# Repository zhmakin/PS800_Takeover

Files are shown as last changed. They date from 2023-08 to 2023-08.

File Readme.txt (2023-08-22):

1. Matlab:
	|..slprj
	|..Buck800w_v1.slx
	|..Buck800w_v1.slxc
	|..sd_setup_v1.m

	*.m - parameter file with model settings 
	*.slx - model file with simulation model

2. Power Inductor design - 3D models of the custom inductor. No design calculation is there. 

3. Releases - folder with the ordering files and fabrication outputs and info we had in the moment of the first version ordering.

4. Ver 2 - Folder with materials collected for second version of the converter. There are RFQs, requirements document, sMath file with calculation design and mostly datasheets for cheapest components available.

5. Manual.pdf - communication and pluging in instruction for the board.

6. Project_STM32G4x.zip - STM CPU firmware project.

7. PS800.zip - PC software to debug and manage the board via USART interface.

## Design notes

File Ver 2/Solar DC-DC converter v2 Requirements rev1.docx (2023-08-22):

Solar DC-DC converter.

Technical requirements

Rev. 0.1

Revision history

Revision level | 0.1
Release date | 12-jul-2023
Status | Draft
Owner | Aleksei Z

Version | Date | Description | Originator
0.1 | 12-jul-2023 | Initial | Aleksei Z

List of abbreviations/acronyms

DC | Direct current
EMC | Electromagnetic compatibility
IP | Ingress protection
PCB | Printed circuit board

1. General requirements
  1.1. Subject of current requirements is a non-isolated bidirectional DCDC power converter for solar application.
  1.2. Converter shall have two sets of terminals to connect two solar PV panels in parallel
  1.3. Converter shall have one set of terminals to connect Li-Ion battery
  1.4. Converter shall have one set of terminals to connect power inverter
  1.5. Minimal cost shall be in priority
  1.6. Interaction with inverter MPPT algorithms is not a subject of current development.
  1.7. The packaging should be made as an open PCB design with heat sink attached
  1.8. Context diagram:

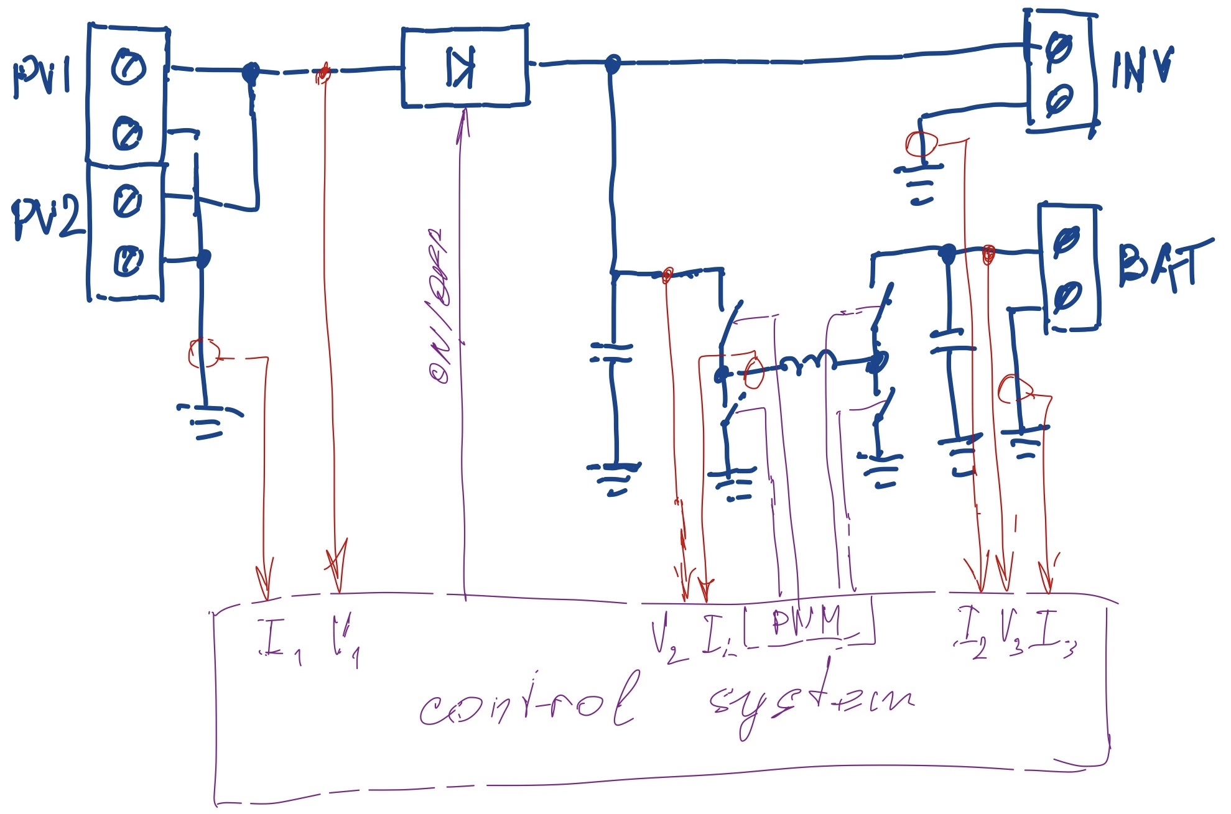
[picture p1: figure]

2. Electrical requirements

# | Parameter | Min | Nom | Max | Units

AA | Inverter output power | | | 900 | W
AB | Inverter output current | | | 30 | A
| 2 x Solar panel RSP450D-120
A | Output voltage | 24 | 34.7 | 43 | V
B | Current total (per panel) | | | 26 (13) | A
| Li-Ion battery (JB-LFP24-100CC as a reference)
C | Battery voltage | 20 | 24 | 26.4 | V
D | Battery charge voltage | | 29 | | V
E | Battery charge current | 1 | | 30 | A
| Power converter set-points
F | PV support voltage | | 34 | | V
G | Short circuit protection delay | | 500 | | us
H | Battery under/overvoltage protection delay | | 500 | | us
I | Overcurrent protection delay | | 1 | | s
J | Overcurrent level | | 110 | | %

3. Environmental requirements
  3.1. Converter shall operate within temperature range of -30°C to +65°C.
  3.2. Converter shall have ingress protection not less than IP54 in line with IEC60529.
4. Functional requirements
    4.1.1. The converter PV input must have “ideal diode” circuitry to prevent reverse current.
  4.1. The converter must have communication interfaces:
    4.1.1. 1 x UART (non-isolated),115 kbps, 8N1, 3.3V-level
    4.1.2. 1 x SPI (non-isolated), 1Mbps, 3.3V-level
  4.2. The converter shall have sufficient modes of operation:
    4.2.1. Battery charge automatic mode (solar to battery and solar to inverter power flows)
      4.2.1.1. Control logic shall provide constant voltage with current limit operation (CV/CC)
      4.2.1.2. Voltage and current set-points should be set via communication interface
      4.2.1.3. Charge mode should start automatically if converter is not in IDLE
      4.2.1.4. MPPT tracking of the PV panels should be implemented
      4.2.1.5. Maximum charge power set-point shall be set via communication interface
    4.2.2. PV support mode (battery to inverter power node)
      4.2.2.1. The control strategy shall be constant voltage with current limit operation (CV/CC).
      4.2.2.2. Transition to this mode and voltage/current set-points are managed via communication interface.
    4.2.3. Converter IDLE mode (Inverter supplied with solar power only)
      4.2.3.1. Transition to IDLE shall be available via communication interface command or by the protection logic.
      4.2.3.2. Only transition via communication interface command to another mode of operation is possible.
  4.3. The converter shall have protection functionality
    4.3.1. Short circuit protection

The control logic shall shutoff the converter in 2.E after short circuit is determined. Protection reset via communication interface shall be implemented.

    4.3.2. Battery undervoltage protection

Stop discharge if battery voltage reached its minimum value for more than 2.H. No automatic transition to another mode.

    4.3.3. Battery overvoltage protection

Stop charge if battery voltage goes at least 0.1V above maximum charge voltage level (2.D) during more than 2.H

    4.3.4. Reverse current to PV panels protection
    4.3.5. Overcurrent protection
      4.3.5.1. The converter shall go to IDLE mode if overcurrent level 2.J reached and kept during more than 2.I
      4.3.5.2. Protection reset shall be available via communication interface only
5. Mechanical requirements
  5.1. All terminals shall be placed along bottom side of the PCB (assumed wall mounted device)
  5.2. Natural convection only shall be used to cool down
  5.3. Power stage shall be designed on separated PCB
  5.4. Cable glands can be used to comply with IP rating

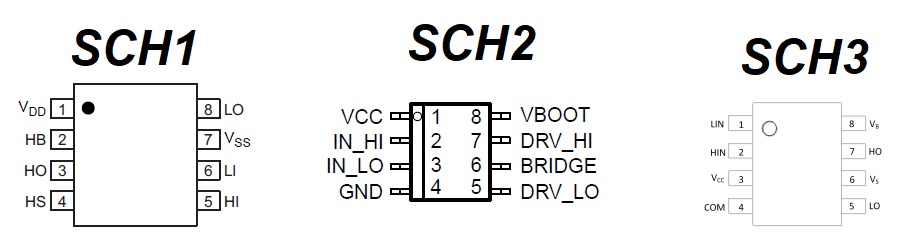
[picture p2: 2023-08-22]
Ver 2/Parts/Drivers/Schematics.jpg

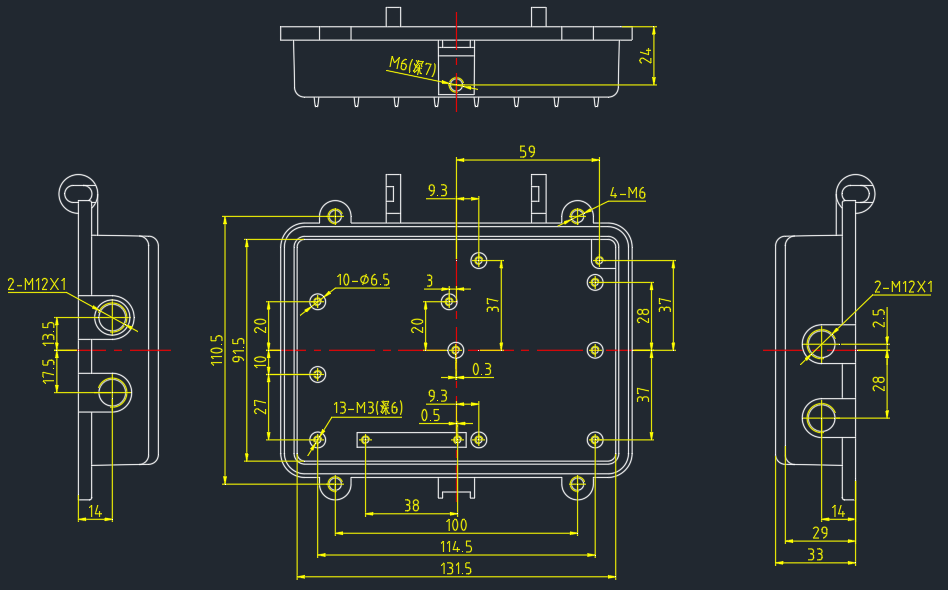
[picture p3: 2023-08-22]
Ver 2/RFQ/He95bb1689c3447e7890ed621c03901dcM.png

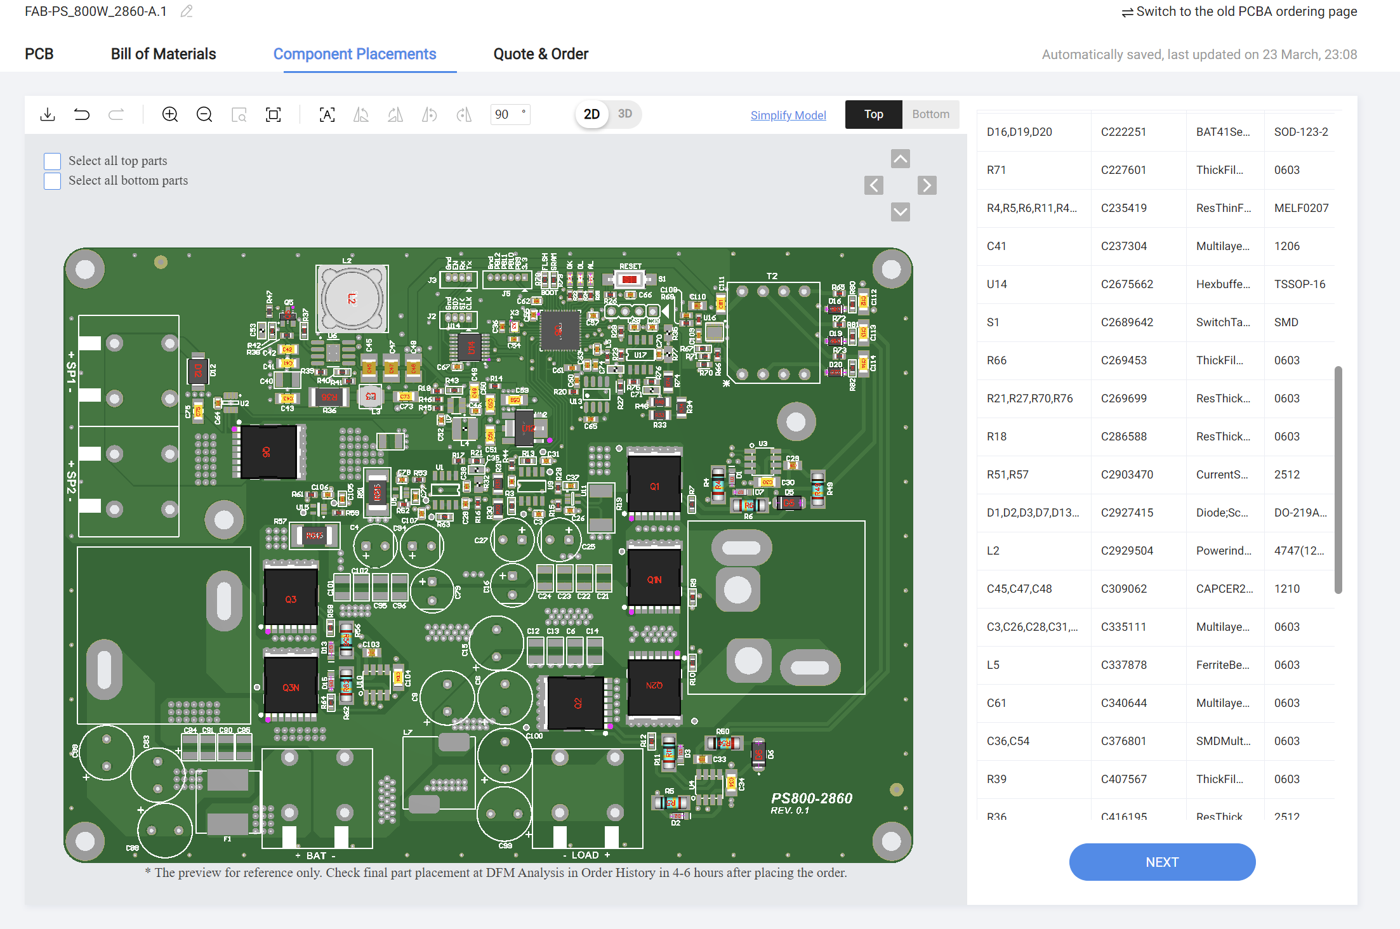
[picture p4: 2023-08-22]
Releases/01/Screenshot_1.png

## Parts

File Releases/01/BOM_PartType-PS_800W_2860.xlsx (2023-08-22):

Designator | Part Number | Footprint | Comment | Quantity
C1, C2, C81 | C3216C0G2E682J160AA | 1206 | Multilayer Ceramic Capacitors MLCC - SMD/SMT 1206 250V 6800pF C0G 5% T: 1.6mm | 3
C3, C26, C28, C31, C38, C39, C44, C46, C52, C55, C56, C57, C62, C63, C64, C66, C67, C68, C69, C70, C78, C106, C107 | C1608X7R1H104K080AA | 0603 | Multilayer Ceramic Capacitors MLCC - SMD/SMT 0603 50VDC 0.1uF 10% X7R 0.8mm | 23
C5, C11, C17, C18, C43, C73, C75, C80, C86, C92, C97 | CC1206KKX7R0BB104 | 1206 | Multilayer Ceramic Capacitors MLCC - SMD/SMT 100V 0.1uF X7R 1206 10% | 11
C6, C12, C13, C14, C21, C22, C23, C24, C40, C76, C84, C85, C90, C91, C95, C96, C101, C102 | C3225X7R2A106K250AC | 1210 | Multilayer Ceramic Capacitors MLCC - SMD/SMT 1210 100VDC 10uF 10% X7R | 18
C7, C20, C41, C82, C93 | GRM31CC72A475KE11L | 1206 | Multilayer Ceramic Capacitors MLCC - SMD/SMT 4.7UF 100V 10% 1206 | 5
C10, C19, C42, C87, C98 | GRM31MR72A684KA35L | 1206 | Multilayer Ceramic Capacitors MLCC - SMD/SMT 0.68uF 100VDC 10% X7R | 5
C29, C33, C103, C110 | CL21B225KAFNNNF | 0805 | Multilayer Ceramic Capacitors MLCC - SMD/SMT 2.2uF+/-10% 25V X7R 0805 | 4
C30, C34, C59, C104, C112, C113, C114 | CL31B475KAHNNNF | 1206 | Multilayer Ceramic Capacitors MLCC - SMD/SMT 4.7uF+/-10% 25V X7R 1206 | 7
C32, C35, C53, C71 | CC0603JPX7R9BB103 | 0603 | Cap Ceramic 0.01uF 50V X7R 5% SMD 0603 125C Paper T/R | 4
C36, C54 | 06035A6R8CAT2A | 0603 | SMD Multilayer Ceramic Capacitor, 6.8 pF, 0.25pF, C0G / NP0, 50 V, 0603 [1608 Metric] | 2
C37, C77, C105 | CC0603JRNPO9BN471 | 0603 | Multilayer Ceramic Capacitors MLCC - SMD/SMT 470PF 50V 5% 0603 | 3
C45, C47, C48 | CL32B226KAJNNNE | 1210 | CAP CER 22UF 25V 10% X7R 1210 | 3
C49, C50, C51, C58, C111 | CL31B106KAHNNNE | 1206 | CL31 Series 10 uF 25 V ±10 % Tolerance X7R SMT Multilayer Ceramic Capacitor | 5
C60, C65 | CL10B225KP8NNNC | 0603 | Ceramic capacitor SMD 0603 2.2 µF 10 V 10 % Samsung Electro-Mechanics CL10B225KP8NNNC 4000 pc(s) | 2
C61 | 0603N102J500CT | 0603 | Multilayer Ceramic Capacitor, 1000 pF, 5%, C0G / NP0, 50 V, 0603 [1608 Metric] | 1
C72 | 08052C472KAT2A | 0805 | CAP CER 4700PF 200V 10% X7R 0805 | 1
C74 | CL10B105MO8NNWC | 0603 | Prices include import duty and tax. CAP, 1UF, 16V, MLCC, 0603; SVHC: No SVHC (15-Jan-2019) | 1
C108 | C0603C682K5RACTU | 0603 | 0603 X7R ceramic capacitor, 50V 6.8nF | 1
C109 | 06033C473KAT4A | 0603 | Multilayer Ceramic Capacitors MLCC - SMD/SMT 25volts 0.047uF 10% X7R | 1
D1, D2, D3, D7, D13, D15, D18 | MSS1P6-M3/89A | DO-219AD-2 | Diode; Schottky Barrier; Vr 60V; If 1A; Pkg MicroSMP; Vf 0.52V; Cj 40pF; Tj +150degc | 7
D4 | LTST-C190KSKT | 0603 | Standard LEDs - SMD Yellow Clear 587nm | 1
D8 | LTST-C190KGKT | 0603 | Standard LEDs - SMD Green Clear 571nm | 1
D10 | LTST-C190KRKT | 0603 | Standard LEDs - SMD Red Clear 631nm | 1
D5, D6, D14 | SS1H10-E3/5AT | SMA (DO-214AC) | 100V 1A | 3
D12 | SMBJ48CA | DO-214AA-2 | Diode Transient Voltage Suppressor Single Directional 48 Volt 600W 2-Pin DO-214AA Tape and Reel | 1
D16, D19, D20 | BAT41ZFILM | SOD-123-2 | BAT41 Series 200 mA 1 V Schottky Diode Surface Mount - SOD-123 | 3
D17 | BZD27C27P-E3-08 | DO-219AB-2 | Diode Zener Single 27V 800mW 2-Pin DO-219AB T/R | 1
F1 | 3-139-124 | SMD | Fuse, Fast-Acting, SMD, High-Current, 80V DC, 60A, UHP Series | 1
L2 | MSS1210-683MEB | 4747 (1212 metric) | Power inductor, shielded, 10/20% tol, SMT, RoHS | 1
L3 | NRS4018T100MDGJ | 4018 | Inductor Power Shielded Wirewound 10uH 20% 100KHz Ferrite 1.2A 180mOhm DCR 1515 T/R | 1
L4 | NRS4018T3R3MDGJ | 4018 | Inductor Power Shielded Wirewound 3.3uH 20% 100KHz Ferrite 2A 66mOhm DCR 1515 T/R | 1
L5 | BLM18AG151SH1D | 0603 | Ferrite Beads Multi-Layer 150Ohm 25% 100MHz 500mA 250mOhm DCR 0603 Paper T/R | 1
L7 | 7443091100 | SMD | WE-HCM SMT High Current Flat Wire Inductor | 1
Q1, Q1N, Q2, Q2N, Q3, Q3N, Q6 | FDBL86066-F085 | TO-LL8-8 | N-Channel PowerTrench® MOSFET, 80V, 300A, 1.4mΩ | 7
Q5 | 2N7002-7-F | SOT-23-3 | 2N7002-7-F N-Channel MOSFET, 115 mA, 60 V, 3-Pin SOT-23 Diodes Inc | 1
R1, R2, R4, R5, R6, R11, R49, R50, R55, R56, R60, R62 | MMB02070C3008FB200 | MELF 0207 | Res Thin Film 0207(2309) 3 Ohm 1% 0.4W ±50ppm/C Conformal Melf SMD Automotive Medical Blister T/R | 12
R3, R7, R9, R10, R12, R13, R37, R40, R42, R43, R58, R63, R64, R67, R78, R79, R80, R81, R82 | RK73H1JTTD1002F | 0603 | Resistor Thick Film 0603 10K Ohm 1% 1/10W ±100ppm/°C SMD Punched Paper Tape and Reel | 19
R14 | RC0603JR-100RL | 0603 | YAGEO RC0603JR-100RL THICK FILM RESISTOR, 0 OHM, 100mW, 5% | 1
R15, R16, R28, R44, R53, R61, R65, R72, R73 | RC0603FR-071RL | 0603 | Res Thick Film 1.6 x 0.8 mm 1 Ohm 1% 0.1W(1/10W) 200ppm/ C Molded SMD Paper T/R | 9
R17, R23, R26, R29, R47, R52, R59, R75 | AC0603FR-13100RL | 0603 | AC Series 0603 100 Ohm ±1 % 0.1 W ±100 ppm/°C Surface Mount Thick Film Resistor | 8
R18 | ERJ-3EKF4022V | 0603 | Res Thick Film 1.6 x 0.8 mm 40.2K Ohm 1% 0.1W(1/10W) 100ppm/ C Molded SMD Punched Carrier T/R | 1
R19 | LRMAP2512-R00075FT4 | 2512 | Current Sense Resistors - SMD 3W 0.0007 Ohm 1% | 1
R51, R57 | LRMAP2512-R001FT4 | 2512 | Current Sense Resistors - SMD 3W 1 mOhm 1% Metal Strip resistor | 2
R20 | CRCW060350R0FKEA | 0603 | Thick Film Resistors - SMD 1/10watt 50ohms 1% Non Std Qt Req'd | 1
R21, R27, R70, R76 | CRCW0603100KFKEAC | 0603 | Res Thick Film 0603 100K Ohm 1% 1/10W ±100ppm/°C Molded SMD Paper T/R | 4
R22, R24, R25 | RK73H1JTTD2550F | 0603 | Thick Film Resistors - SMD 1/10watts 255ohms 1% | 3
R69 | RK73H1JTTD6493F | 0603 | Thick Film Resistors - SMD 1/10watt 649Kohms 1% | 1
R71 | RK73H1JTTD1542F | 0603 | Thick Film Resistors - SMD 1/10watts 15.4Kohms | 1
R30, R31, R33, R34 | RT1206DRE0710KL | 1206 | Thin Film Resistors - SMD | 4
R48, R74 | RT1206DRE0715KL | 1206 | Thin Film Resistors - SMD 15K OHM .5% 50PPM 1/4W | 2
R32, R35, R77 | ERJ-PB6B1001V | 0805 | Res Thick Film 0805 1K Ohm 0.1% 0.25W(1/4W) ±50ppm/C Pad SMD | 3
R36 | RMCF2512FT1R00 | 2512 | Res Thick Film 2512 1 Ohm 1% 1W ±400ppm/°C Molded SMD SMD Plastic T/R | 1
R38 | RC0603JR-07130KL | 0603 | Thick Film Resistors - SMD 130K OHM 5% | 1
R39 | RK73H1JTTD6492F | 0603 | Thick Film Resistors - SMD 1/10watts 64.9Kohms | 1
R41 | RK73H1JTTD1103F | 0603 | Res Thick Film 0603 110K Ohm 1% 0.1W(1/10W) ±100ppm/C Molded SMD Automotive Punched Paper T/R | 1
R66 | RK73H1JTTD1243F | 0603 | Thick Film Resistors - SMD 1/10watt 124Kohms 1% | 1
R68 | RK73H1JTTD5902F | 0603 | Thick Film Resistors - SMD 1/10watts 59Kohms 1% | 1
R45 | AC0603FR-0727KL | 0603 | Thick Film Resistors - SMD 1/10W 27K ohm 1% | 1
R46 | ERJ-3EKF2003V | 0603 | Res Thick Film 0603 200K Ohm 1% 0.1W(1/10W) ??? }100ppm/??? Molded SMD Automotive Punched T/R | 1
R83 | SMA-A0204FTDX330R | MELF 0204 | Res Thin Film 0204(1406) 330 Ohm 1% 0.25W(1/4W) ±50ppm/C Melf Pad SMD Automotive Medical T/R | 1
S1 | PTS636 SL43 SMTR LFS | SMD | Switch Tactile N.O. SPST Rectangular Button Gull Wing 0.05A 12VDC 1.27N SMD T/R | 1
U1, U9, U17 | LM2904LVIDR | SOIC-8 | Dual, 5.5-V, 1-MHz, 3-mV offset voltage operational amplifier 8-SOIC -40 to 125 | 3
U2 | LM74700MDDFREP | SOT-23-THIN-8 | Enhanced low IQ ideal diode controller 8-SOT-23-THIN -50 to 125 | 1
U3, U4, U10 | DGD2190MS8-13 | SOIC-8 | Gate Driver IC, 2 Ch, 10V-20V, SOIC Rohs Compliant: Yes | 3
U5, U11, U15 | INA290A2IDCKT | SC-70 | 2.7 to 120V, 1.1MHz, ultra-precise current sense amplifier in small (SC-70) package 5-SC70 -40 to 125 | 3
U6 | LMR38010FDDAR | SO-PowerPAD-8 | Switching Regulator, Current-mode, 1A, 2200kHz Switching Freq-Max, PDSO8 | 1
U7 | AP62150WU-7 | TSOT26 | DC to DC Converter Adjustable Synchronous Buck 0.8V to 7V 1.5A 6-Pin TSOT-26 T/R | 1
U8 | STM32G431CBU3 | UFQFPN-48 | MCU 32-Bit STM32G431 ARM Cortex-M4 RISC 128KB Flash 1.71V to 3.6V 48-Pin UFQFPN Tray | 1
U12 | AP7365-33ERG-13 | SOT-223R-3 | LDO Regulator Pos 3.3V 0.6A 4-Pin(3+Tab) SOT-223 T/R | 1
U13 | MCP1501-30E/SN | SOIC-8 | Microchip MCP1501-30E/SN, Fixed Series Voltage Reference 3V, ±0.08 % 8-Pin, SOIC | 1
U14 | SN74HCS365PWR | TSSOP-16 | Hex buffers and line drivers with 3-state outputs 16-TSSOP -40 to 125 | 1
U16 | MAX17692AATC | TDFN-EP | MAX17692A 4.2V to 60V, No-Opto Isolated Flyback Converter Evaluation Kit | 1
X3 | NX2016SA-24MHZ | 4-SMD | Crystal 24.0000MHZ 6PF SMD | 1
X1, X2, X4, X5 | VP0265840000G | TRH | Fixed Terminal Blocks TB RIS CLA SINGLE/T | 4
L1, L6 | CPEX3231A-270MC | TRH | 27 µH Shielded Wirewound Inductor 41.4 A 1.86mOhm Max Vertical, 2 PC Pin | 2
T1 | CUSTOM TRANSFORMER | TRH | Flybuck custom transformer | 1
C4, C79, C94, C16, C25, C27 | EEU-FS1J181L | TRH | Aluminium Electrolytic Capacitors - Radial Leaded 63VDC 180uF 20% Polar Radial | 6
C8, C9, C15, C99, C100, C83, C88, C89 | UHE2A101MPD1TD | TRH | Aluminium Electrolytic Capacitors - Radial Leaded 100uF 100 Volts 20% | 8
J5 | 53047-0610 | TRH | Headers & Wire Housings VERTICAL HDR 6P | 1
J2, J3 | 53047-0410 | TRH | Headers & Wire Housings VERTICAL HDR 4P | 2

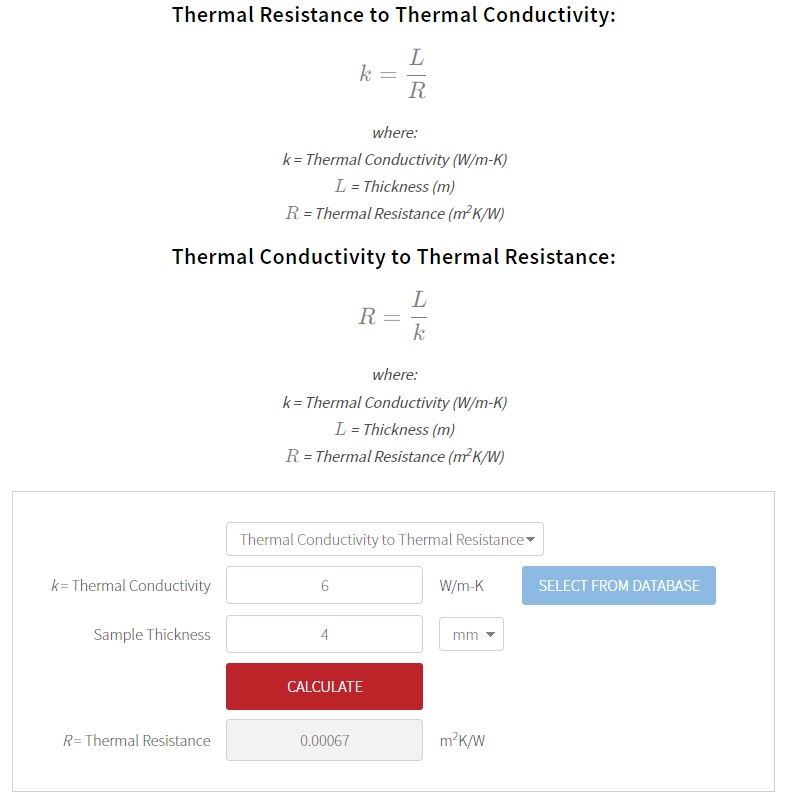
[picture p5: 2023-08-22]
Ver 2/Parts/Thermal resistance from Conductivity.jpg

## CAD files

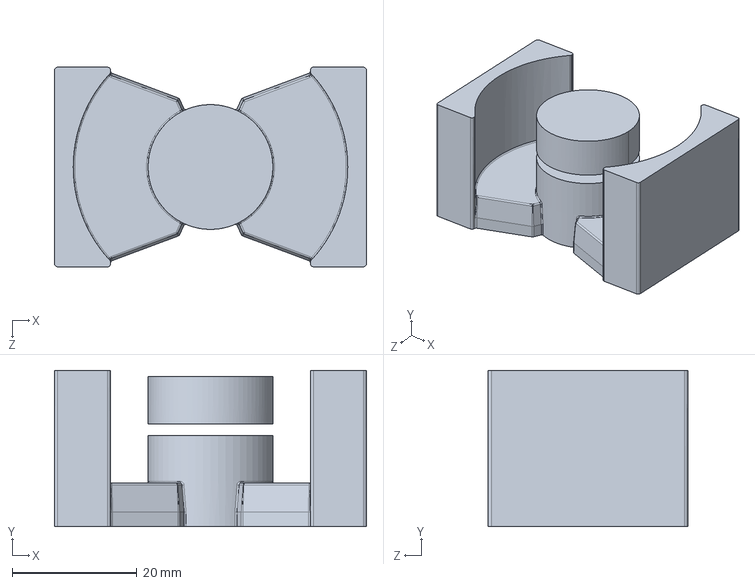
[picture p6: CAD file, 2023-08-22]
Power Inductor design/pq50_50-dg100-n95_n97.step.SLDPRT
50.0 x 25.0 x 32.0 mm

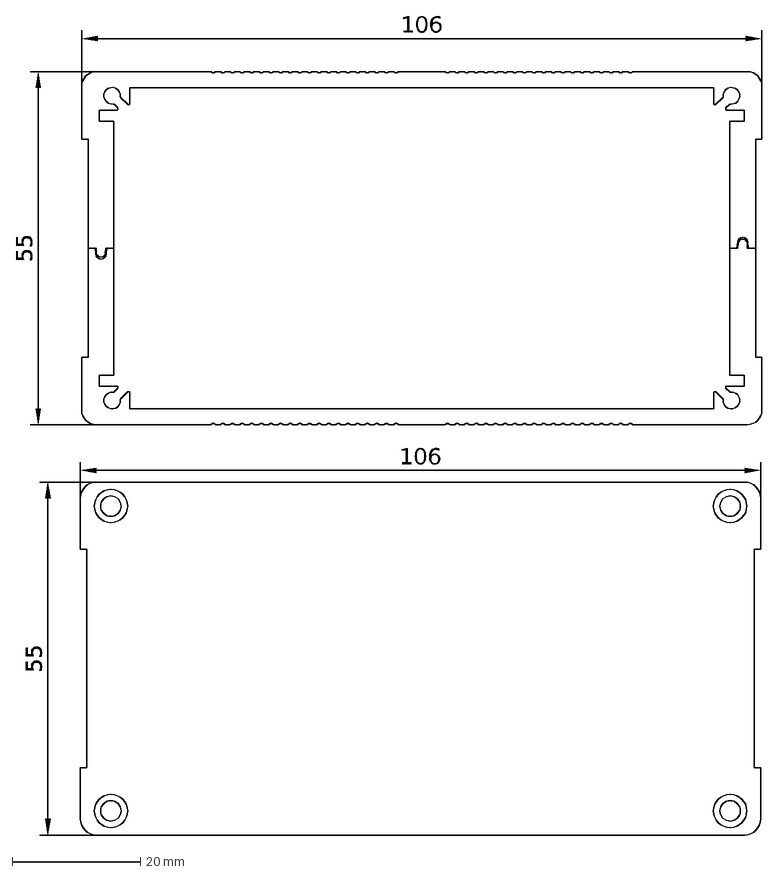
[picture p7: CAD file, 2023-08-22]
Ver 2/RFQ/HLT-0001.dxf
106
55

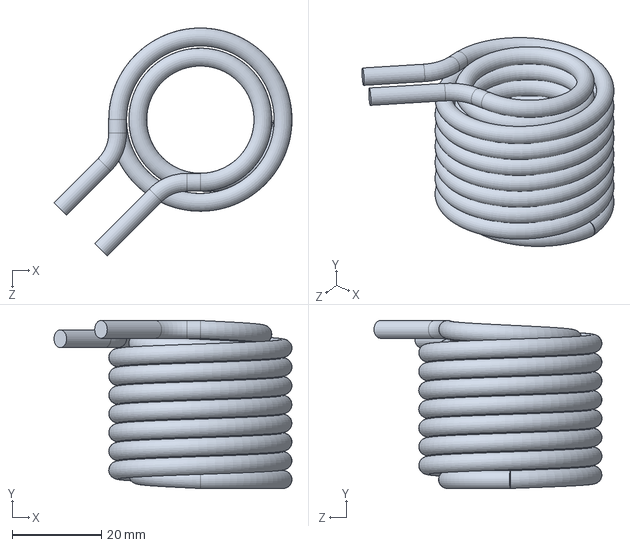
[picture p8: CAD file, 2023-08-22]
Power Inductor design/Round wire 4mm 16t.SLDPRT
53.2 x 37.6 x 51.0 mm

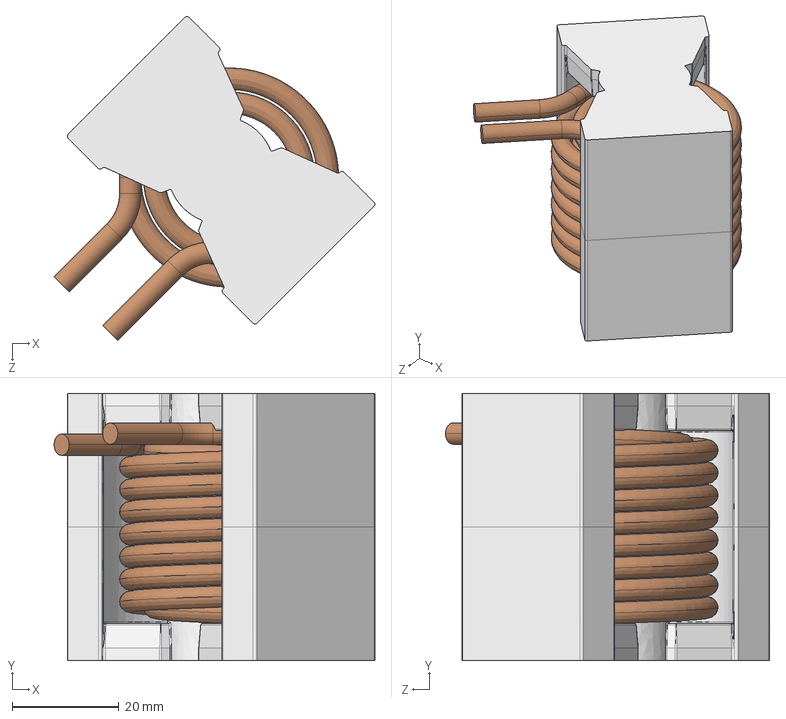
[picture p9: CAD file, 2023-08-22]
Power Inductor design/PQ50_16T_INDUCTOR_V1.STEP
60.0 x 50.0 x 60.6 mm
Round wire 4mm 16t
pq50_50-dg100-n95_n97.step x 2

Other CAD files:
Power Inductor design/pq50_50-dg100-n95_n97.step
Ver 2/RFQ/A-016底-D.dwg
Ver 2/RFQ/DAM016.dwg
Ver 2/RFQ/DAM001C.dwg
Power Inductor design/PQ50_16T_INDUCTOR_V1.SLDASM

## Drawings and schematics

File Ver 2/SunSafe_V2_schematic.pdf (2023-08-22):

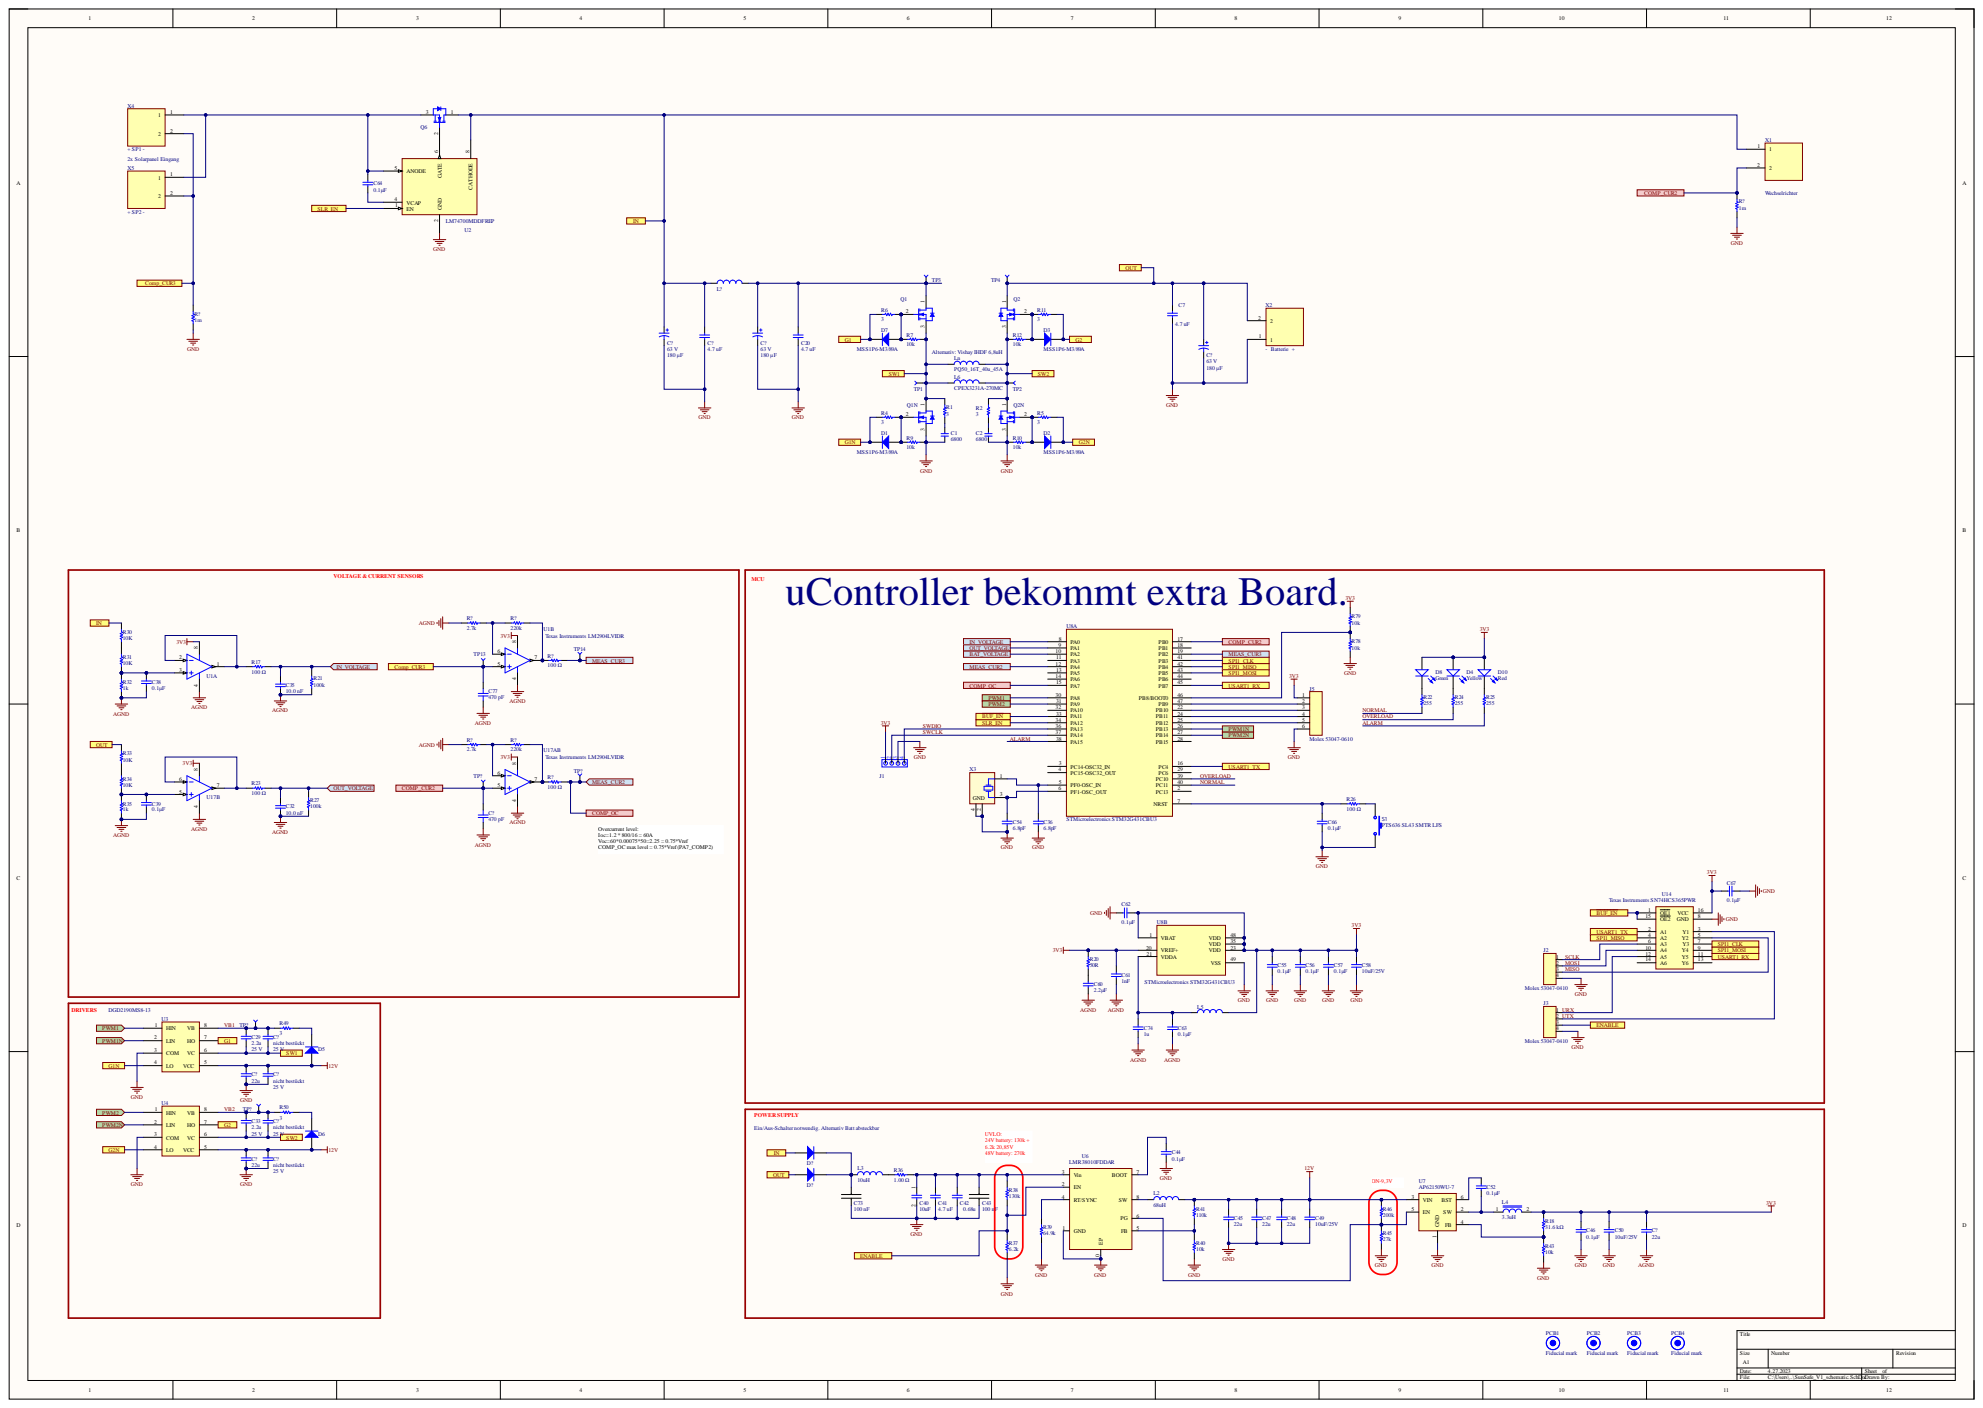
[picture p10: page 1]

uController bekommt extra Board.

Ein/Aus-Schalter notwendig. Alternativ Batt absteckbar

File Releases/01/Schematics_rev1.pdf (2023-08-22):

# AGND OUT

# R58 G³

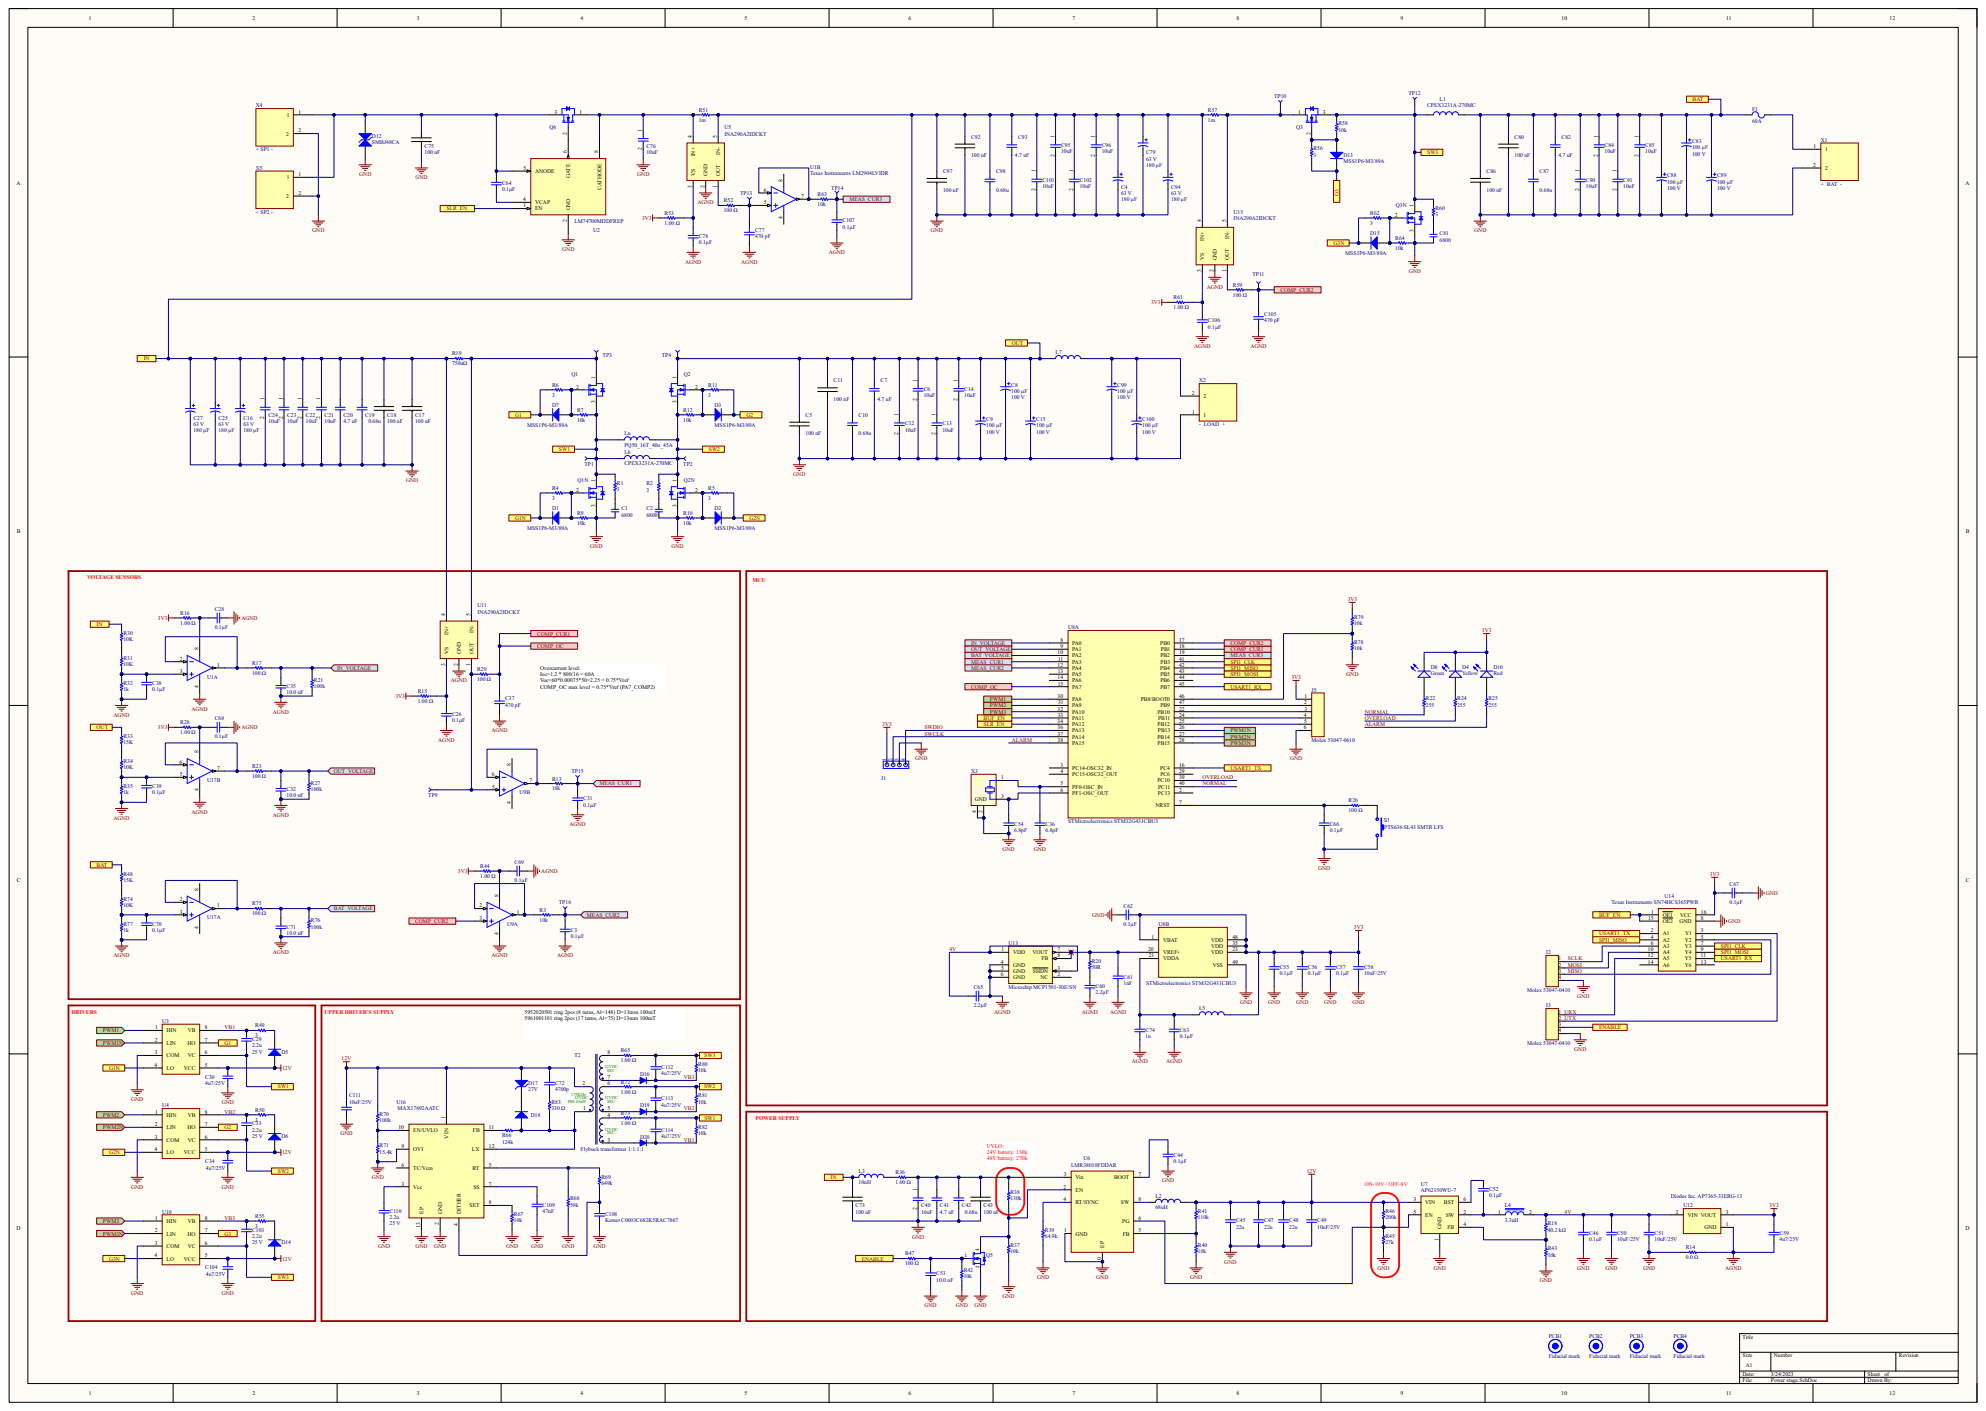
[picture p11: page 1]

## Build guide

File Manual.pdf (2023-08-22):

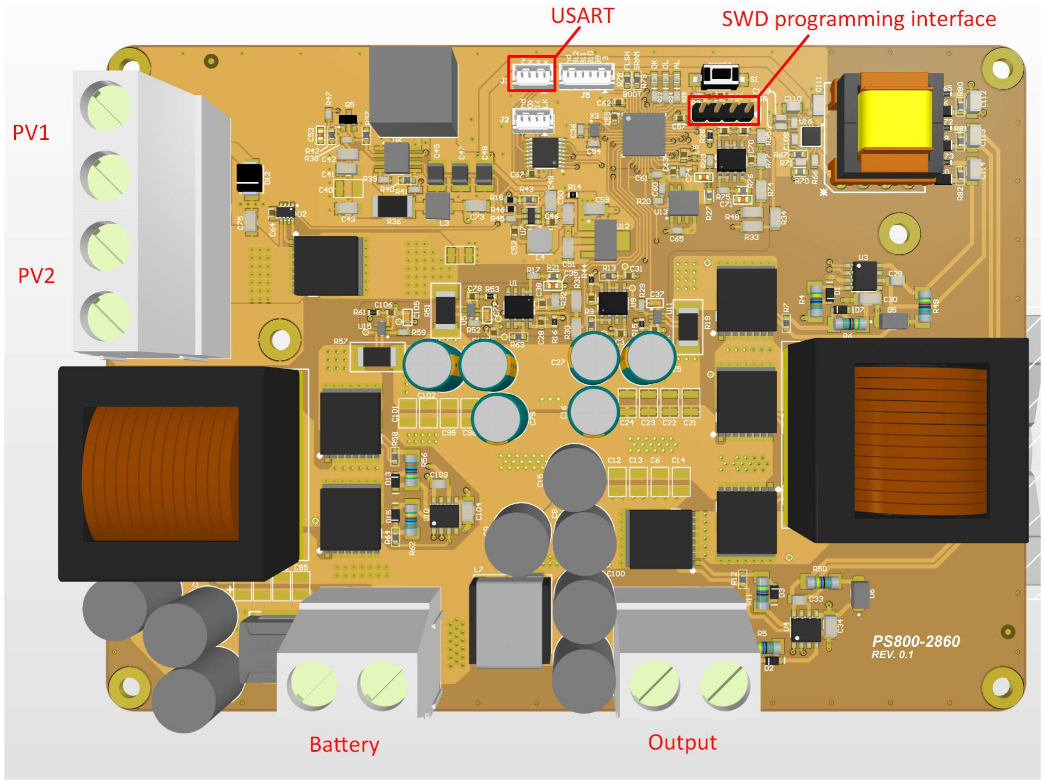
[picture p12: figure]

## SWD programming interface pinout:

Pin | Funcon | Note
1 | +3.3V | From board
2 | SWDCLK | IN
3 GND
4 | SWDIO | I/O

## USART interface pinout:

Pin | Funcon | Note
1 | RX | In
2 | TX | Out
3 | nENABLE | Turn off the board power supply. +3…+20V

4 GND

## UART paired device must not exceed 3.3V “high” logic level voltage

## USART sengs:

N | Funcon | Value
1 | Speed | 115200 bps
2 | Stop bit | 1
3 | Parity | N
4 | Data bits | 8

## USART commands:

N | Funcon | Example* | Respond | Descripon
1 | Start pool | 03AAFFFFFFFF8B, where 03 AA - command FF FF FF FF - payload 8B – CRC8 | 33 bytes in total: 0000 [30 data bytes] CRC8 30 data bytes can be filled by any data needed Currently realized: 0x0000 – nonfunconal bytes 0xNNNN – PV voltage x100 0xNNNN – Bat voltage x100 0xNNNN – Bat current x100 0x0000 – non funconal 0xNNNN – ERROR1 x100 0xNNNN – P1 component x100 0xNNNN – I1 component x100 0xNNNN – I1 clamp value x100 0xNNNN – PI1 saturaon x100 0x0000 … not filled 0x0000 0xNN – CRC8 | Starts or stops periodical data sending every 10ms me interval. The scope is firmware determined.
2 | Disable | 00AAFFFFFFFFF0, where 00 AA - command FF FF FF FF - payload F0 – CRC8 | No respond | Turns off all the switches, measurements funcons keep working.
3 | Discharge | 02AAFFFFFFFFA2, where 02 AA – command FF FF FF FF - payload A2 – CRC8 | No respond | Turns top switch on and gives the baery voltage supply the output. Board goes to this mode only if Vin < Vbat.
4 | Charge | 01AA0000000007, where 01 AA - command 0x0000 –voltage setpoint x100 0x0000 – current setpoint x100 07 – CRC8 Example of 28.8V and 1A limit: 01AA400B6400D1, where: 01AA – command 400B – (28.8 * 100) in LE order 6400 - (1 * 100) in LE order D1 – CRC8 | No respond | Starts power flow from PV inputs to the baery. Voltage stabilized if the current below limit otherwise the voltage is current determined. Board goes to this mode only if Vbat < (voltage setpoint)

## *-CRC8 polynomic value is 0x07

The board does not have an appropriate cooling system since it is the prototype stage. Keep the MOSFET’s temperature below 130C during operaon.
The board starts in “Disable” mode on power up.
